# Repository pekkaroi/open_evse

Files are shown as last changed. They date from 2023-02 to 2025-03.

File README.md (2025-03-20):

# OpenEVSE

My fork has support for two contactors - one for 1 phase and one for 3 phase, and user can select the relay before starting charging. Change of the relay is forbidden during charging. To change the number of phases (to match with excess solar production), I have implemented a EspHome component connected to my OpenEvse directly with uart, and it first disables the charger (sleep), changes the relay to use, and then re-enables charge.

Additionally, as I accidentially ordered AtMega 328pb chips instead of 328p for my build, I had to modify the source accordinly.

Firmware for OpenEVSE controller used in OpenEVSE Charging Stations sold in the USA, and OpenEnergyMonitor EmonEVSE units sold in (UK/EU).

- OpenEVSE: <https://store.openevse.com/collections/all-products>
- EmonEVSE: <https://shop.openenergymonitor.com/evse/>

Based on OpenEVSE: Open Source Hardware J1772 Electric Vehicle Supply Equipment

## USA

TODO: add notes about USA OpenEVSE

## UK/EU

- Disable `AUTOSVCLEVEL` (autodetection is designed for split-phase)
- Charging level default to `L2`
- Set `MAX_CURRENT_CAPACITY_L2 32` (limit for single-phase charging in UK/EU)
- Add '.EU' to version number
- Enable LCD Redraw every couple of min (required for EMC/CE)

### EmonEVSE

EmonEVSE (non-tethered type-2 EVSE unit)

- `PP_AUTO_AMPACITY` enabled to set max current based on non-tethered cable connected
- Three-phase option with `THREEPHASE` enabled to calculate three-phase energy ( Unneeded with ESP32_WiFi firmware >= 4.2

## API Documentation

- WIFI API: <http://github.com/openevse/ESP32_WiFi_V4.x/>
- RAPI API: <https://github.com/openenergymonitor/open_evse/blob/master/firmware/open_evse/rapi_proc.h>

## Resources

- [OpenEnergyMonitor OpenEVSE Setup Guide](https://guide.openenergymonitor.org/integrations/openevse)
- [OpenEnergyMonitor OpenEVSE Shop](https://shop.openenergymonitor.com/ev-charging/)

- [OpenEVSE Controller Datasheet](https://github.com/OpenEVSE/OpenEVSE_PLUS/blob/master/OpenEVSE_PLUS_v5/OpenEVSE_Plus_v5.pdf)
- [OpenEVSE Controller Hardware Repo](https://github.com/OpenEVSE/OpenEVSE_PLUS)
- [OpenEVSE Project Homepage](https://openevse.com)

***

Firmware compile & upload help: [firmware/open_evse/LoadingFirmware.md](firmware/open_evse/LoadingFirmware.md)

NOTES:

- Working versions of the required libraries are included with the firmware code. This avoids potential issues related to using the wrong versions of the libraries.
- Highly recommend using the tested pre-compiled firmware (see releases page)

## Flash pre-compiled using avrdude

`$ avrdude -p atmega328p -B6 -c usbasp -P usb -e -U flash:w:firmware.hex`

ISP programmer required e.g [USBASP](https://www.amazon.co.uk/Hobby-Components-USBASP-Programmer-Adapter/dp/B06XYV162N)

### Set AVR fuses

This only needs to be done once in the factory

`avrdude -c USBasp -p m328p -U lfuse:w:0xFF:m -U hfuse:w:0xDF:m -U efuse:w:0xFD:m -B6`

If writing eFuse fails ISBasp may need a [firmware update](https://www.vishnumaiea.in/articles/electronics/how-to-solve-usbasp-avr-efuse-write-problem-on-progisp)

***

Tip Jar: I developed/maintain this firmware on a volunteer basis. Any donation, no matter how small, is greatly appreciated.



```text
Open EVSE is free software; you can redistribute it and/or modify
it under the terms of the GNU General Public License as published by
the Free Software Foundation; either version 3, or (at your option)
any later version.

Open EVSE is distributed in the hope that it will be useful,
but WITHOUT ANY WARRANTY; without even the implied warranty of
MERCHANTABILITY or FITNESS FOR A PARTICULAR PURPOSE.  See the
GNU General Public License for more details.

You should have received a copy of the GNU General Public License
along with Open EVSE; see the file COPYING.  If not, write to the
Free Software Foundation, Inc., 59 Temple Place - Suite 330,
Boston, MA 02111-1307, USA.

* Open EVSE is distributed in the hope that it will be useful,
* but WITHOUT ANY WARRANTY; without even the implied warranty of
* MERCHANTABILITY or FITNESS FOR A PARTICULAR PURPOSE.
```

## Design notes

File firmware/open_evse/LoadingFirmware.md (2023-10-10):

# OpenEVSE Firmware Loading

## Introduction 

Loading firmware to the OpenEVSE requires an ISP. There are many AVR/Arduino compatible programmers available from Adafruit, Sparkfun and the OpenEVSE Store. The instructions below are based on the USBasp.

## USBasp Windows Driver

Current versions of avrdude used by Platform IO and Arduino IDE need the libusbK driver in order to function properly with generic USBasp clones.

1. Plug in USBasp
2. Download Zadig from http://zadig.akeo.ie
3. Start zadig
4. Options > List all devices
5. Select USBasp from the drop down menu
6. Select libusbK(v3.0.7.0) driver
7. Click Install

## Firmware Building and Uploading

The latest firmware source code is located in GitHub: https://github.com/lincomatic/open_evse/tree/development

The latest stable firmware source code is located in GitHub: https://github.com/OpenEVSE/open_evse

### Platform IO

#### 1. Install Platform IO

Either install the command line only [PlatformIO Core](http://docs.platformio.org/en/latest/installation.html) or the download the [PlatfomIO IDE](http://platformio.org/platformio-ide).

If you already have Atom or VS Code installed you can just install the [Atom package](https://atom.io/packages/platformio-ide) or [VSCode extension](https://marketplace.visualstudio.com/items?itemName=platformio.platformio-ide) respectively.

### Arduino IDE

<div class="alert alert-success">
Note: These following instructions have been extracted from Google Code and are not complete/properly edited
</div>

The Arduino IDE includes an code editor, serial monitor, and will compile and upload your code to the OpenEVSE.

Download and install the Arduino IDE from here: http://arduino.cc/en/Main/Software

In the Arduino Software you can simply select the Arduino UNO in the Tools - Boards menu or add a custom entry for OpenEVSE.

Optional - To add a custom board to Arduino IDE, copy the "boards.txt" to the folder ~\Arduino\hardware\openevse\avr.

```
#
open_evse.name=OpenEVSE

open_evse.bootloader.low_fuses=0xFF
open_evse.bootloader.high_fuses=0xDA
open_evse.bootloader.extended_fuses=0x05

open_evse.upload.using=avrispmkii
open_evse.upload.maximum_size=32768

open_evse.build.mcu=atmega328p
open_evse.build.f_cpu=16000000L
open_evse.core=arduino
open_evse.build.variant=standard
```

After you do that (and restart Arduino), you'll find a new entry in your Boards menu called "OpenEVSE". Select that when preparing to upload firmware.

#### 2. Compile

`$ pio run`

The first time platformIO is ran the AVR arduino tool chain and all the required libs will be installed if required.

#### 3. Upload

`$ pio run -t program`

### Setting Fuse Bits

If you are burning virgin chips, you must set the fuse bits prior to programming. Fuses only need to be set once and will retain the settings unless reset. If you've modified boards.txt as shown above, then select "burn bootloader" from the tools menu to set the fuses as appropriate. This step won't actually load a bootloader. It will simply set the fuses.

See also: https://code.google.com/p/open-evse/wiki/AVRDUDE for how to accomplish this.

## Enabling features

To enable a feature delete the `//` in front of the #define tag. To disable a feature add `//`...

Example to enable the Advanced Power Supply features (`ADVPWR`) Change the line:

```
//#define ADVPWR
```

to

```
define ADVPWR
```

Note: Use Extreme caution with WATCHDOG, if delays were added that exceed the timer the EVSE board will reset in an endless loop. It may be very difficult or impossible to recover.

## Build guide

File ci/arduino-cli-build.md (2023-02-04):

# OpenEVSE build via Arduino CLI

Setup

```bash
arduino-cli core update-index
arduino-cli core install arduino:avr@1.6.15
cp arduino/1.6.15/boards.local.txt ~/.arduino15/packages/arduino/hardware/avr/1.6.15/
cp arduino/1.6.15/programmers.txt ~/.arduino15/packages/arduino/hardware/avr/1.6.15/
```

Build

```bash
arduino-cli compile -b arduino:avr:openevse firmware/open_evse
```

Upload

```bash
arduino-cli upload -b arduino:avr:openevse -P usbasp firmware/open_evse -v
```

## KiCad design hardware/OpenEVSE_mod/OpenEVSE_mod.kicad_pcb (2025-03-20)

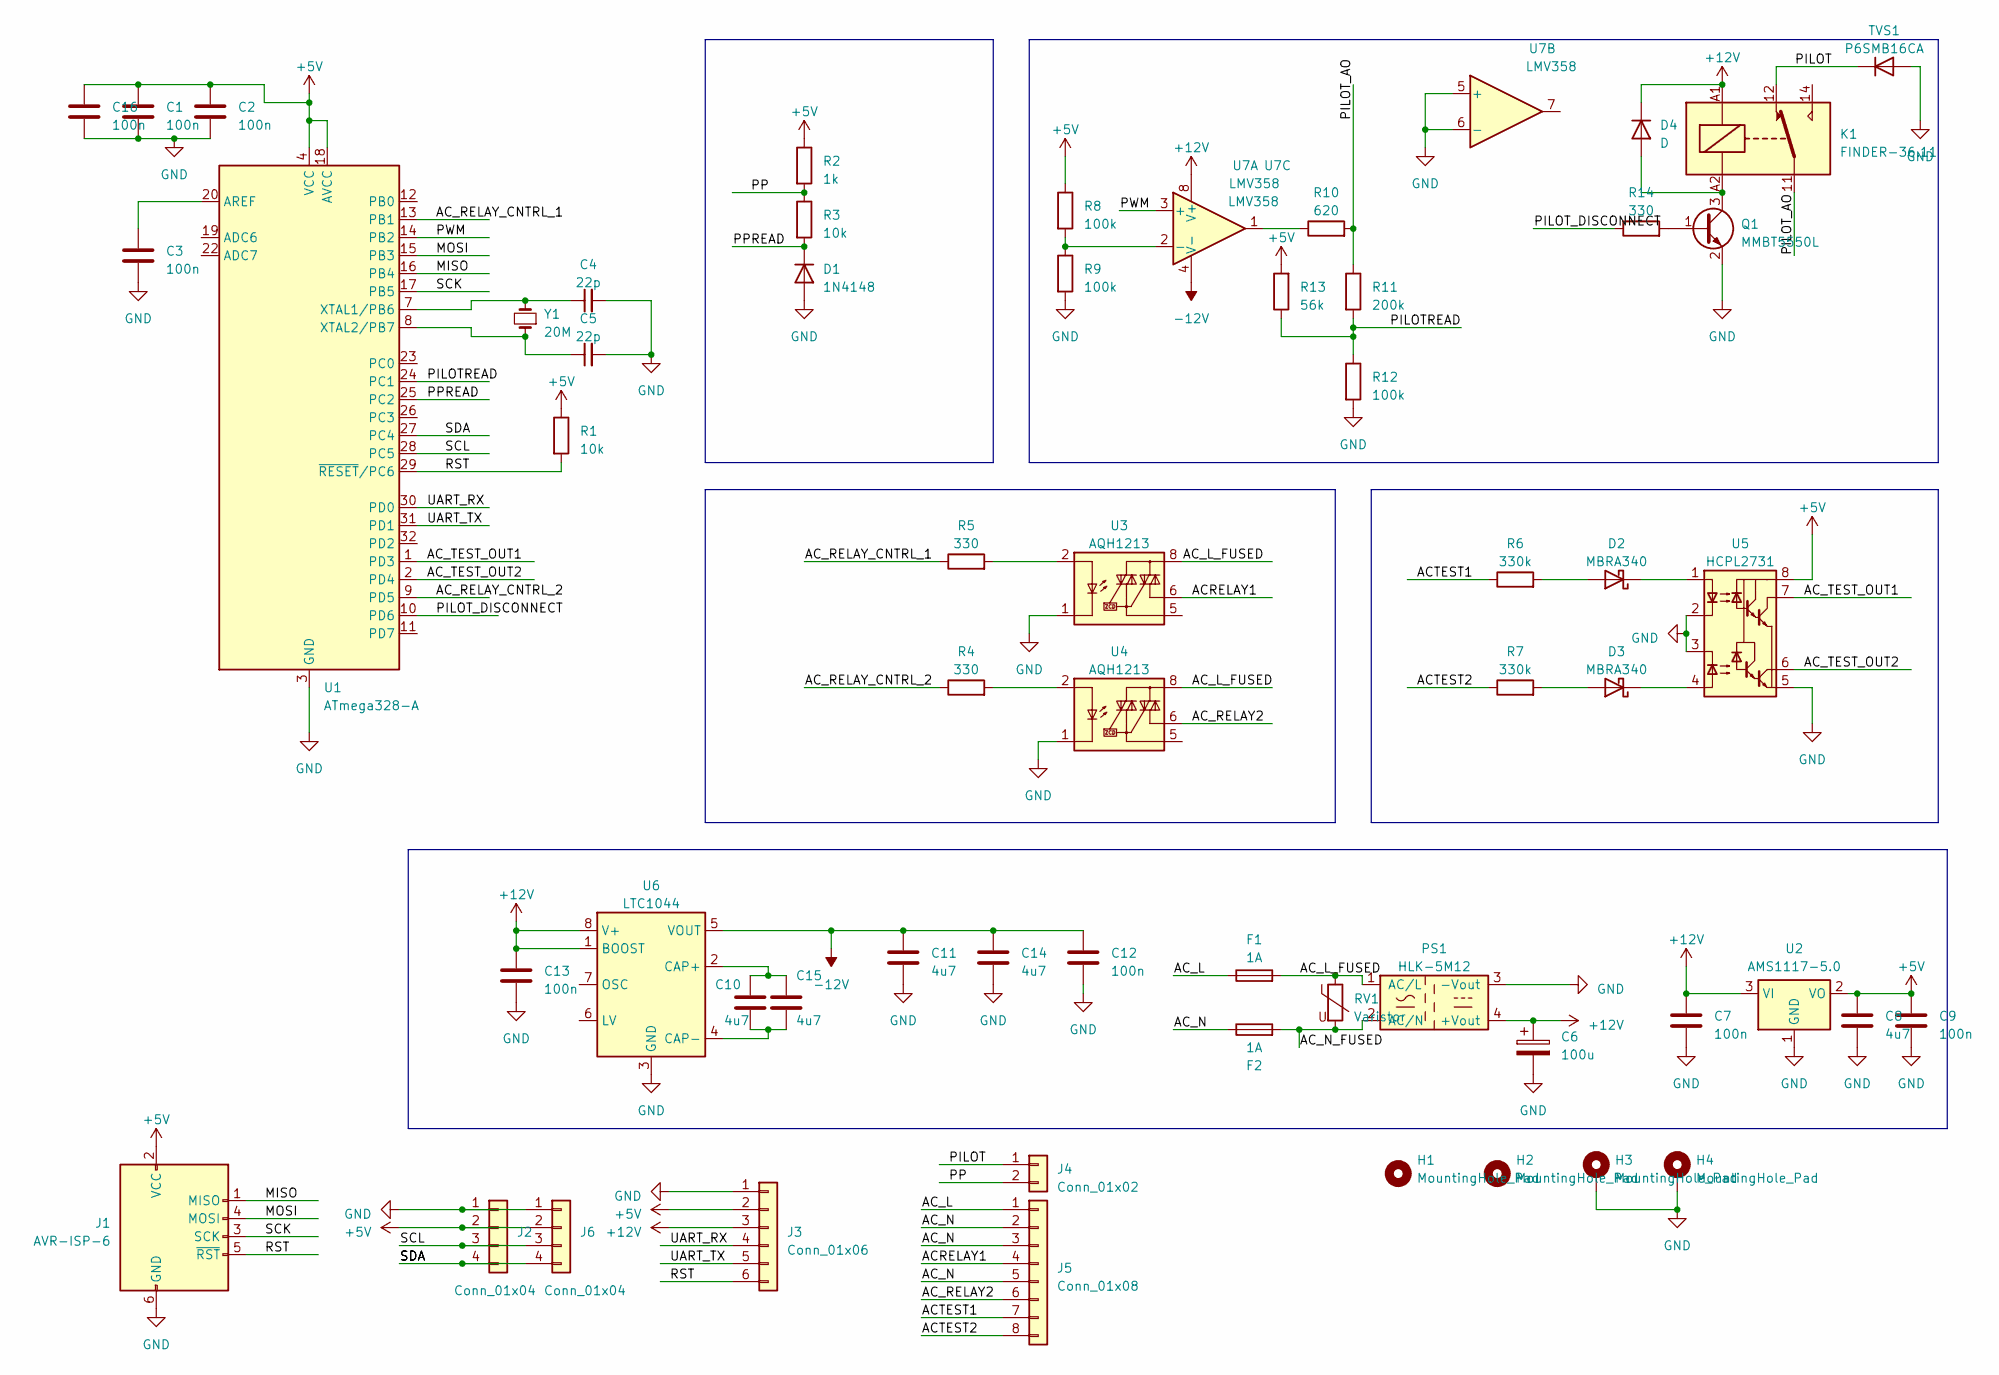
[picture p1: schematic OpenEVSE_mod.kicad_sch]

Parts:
C1, C2, C3, C7, C9, C12, C13, C16: 100n; C_0805_2012Metric_Pad1.18x1.45mm_HandSolder
C4, C5: 22p; C_0805_2012Metric_Pad1.18x1.45mm_HandSolder
C6: 100u; CP_Radial_D8.0mm_P3.50mm
C8, C10, C11, C14, C15: 4u7; C_0805_2012Metric_Pad1.18x1.45mm_HandSolder
D1: 1N4148; D_0402_1005Metric_Pad0.77x0.64mm_HandSolder
D2, D3: MBRA340; D_SMA
D4: D; D_SMB-SMC_Universal_Handsoldering
F1, F2: 1A; Fuse_Littelfuse_395Series
H1, H2: MountingHole_Pad; MountingHole_3.2mm_M3_ISO14580
H3, H4: MountingHole_Pad; MountingHole_3.2mm_M3_ISO14580_Pad_TopBottom
J1: AVR-ISP-6; PinHeader_2x03_P2.54mm_Vertical
J2, J6: Conn_01x04; PinSocket_1x04_P2.54mm_Vertical
J3: Conn_01x06; PinSocket_1x06_P2.54mm_Vertical
J4: Conn_01x02; TerminalBlock_Phoenix_PT-1,5-2-5.0-H_1x02_P5.00mm_Horizontal
J5: Conn_01x08; TerminalBlock_Phoenix_PT-1,5-8-5.0-H_1x08_P5.00mm_Horizontal
K1: FINDER-36.11; Relay_SPDT_Finder_36.11
PS1: HLK-5M12; Converter_ACDC_Hi-Link_HLK-5MXX_THT
Q1: MMBT5550L; SOT-23
R1, R3: 10k; R_0805_2012Metric_Pad1.20x1.40mm_HandSolder
R2: 1k; R_0805_2012Metric_Pad1.20x1.40mm_HandSolder
R4, R5, R14: 330; R_0805_2012Metric_Pad1.20x1.40mm_HandSolder
R6, R7: 330k; R_Axial_DIN0309_L9.0mm_D3.2mm_P15.24mm_Horizontal
R8, R9, R12: 100k; R_0805_2012Metric_Pad1.20x1.40mm_HandSolder
R10: 620; R_0805_2012Metric_Pad1.20x1.40mm_HandSolder
R11: 200k; R_0805_2012Metric_Pad1.20x1.40mm_HandSolder
R13: 56k; R_0805_2012Metric_Pad1.20x1.40mm_HandSolder
RV1: Varistor; RV_Disc_D12mm_W3.9mm_P7.5mm
TVS1: P6SMB16CA; D_SMB_Handsoldering
U1: ATmega328-A; TQFP-32_7x7mm_P0.8mm
U2: AMS1117-5.0; SOT-223-3_TabPin2
U3, U4: AQH1213; DIP-8-N7_W7.62mm
U5: HCPL2731; DIP-8_W7.62mm
U6: LTC1044; SOIC-8_3.9x4.9mm_P1.27mm
U7: LMV358; SOIC-8_3.9x4.9mm_P1.27mm
Y1: 20M; Crystal_HC49-U_Vertical

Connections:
+5V: C1.1, C2.1, C8.1, C9.1, C16.1, J1.2 (VCC), J2.2, J3.2, J6.2, R1.1, R2.1, R8.1, R13.2, U1.4 (VCC), U1.6 (VCC), U1.18 (AVCC), U2.2 (VO), U5.8 (VCC)
+12V: C6.1, C7.1, C13.1, D4.1 (K), J3.3, K1.A1, PS1.4 (+Vout), U2.3 (VI), U6.1 (BOOST), U6.8 (V+), U7.8 (V+)
-12V: C11.1, C12.1, C14.1, U6.5 (VOUT), U7.4 (V-)
/ACRELAY1: J5.4, U3.6
/ACTEST1: J5.7, R6.1
/ACTEST2: J5.8, R7.1
/AC_L: F1.1, J5.1
/AC_L_FUSED: F1.2, PS1.1 (AC/L), RV1.1, U3.8, U4.8
/AC_N: F2.1, J5.2, J5.3, J5.5
/AC_N_FUSED: F2.2, PS1.2 (AC/N), RV1.2
/AC_RELAY2: J5.6, U4.6
/AC_RELAY_CNTRL_1: R5.1, U1.13 (PB1)
/AC_RELAY_CNTRL_2: R4.1, U1.9 (PD5)
/AC_TEST_OUT1: U1.1 (PD3), U5.7 (VO1)
/AC_TEST_OUT2: U1.2 (PD4), U5.6 (VO2)
/MISO: J1.1 (MISO), U1.16 (PB4)
/MOSI: J1.4 (MOSI), U1.15 (PB3)
/PILOT: J4.1, K1.12, TVS1.1 (K)
/PILOTREAD: R11.2, R12.1, R13.1, U1.24 (PC1)
/PILOT_AO: K1.11, R10.2, R11.1
/PILOT_DISCONNECT: R14.1, U1.10 (PD6)
/PP: J4.2, R2.2, R3.1
/PPREAD: D1.1 (K), R3.2, U1.25 (PC2)
/PWM: U1.14 (PB2), U7.3 (+)
/RST: J1.5 (~RST), J3.6, R1.2, U1.29 (~RESET/PC6)
/SCK: J1.3 (SCK), U1.17 (PB5)
/SCL: J2.3, J6.3, U1.28 (PC5)
/SDA: J2.4, J6.4, U1.27 (PC4)
/UART_RX: J3.4, U1.30 (PD0)
/UART_TX: J3.5, U1.31 (PD1)
GND: C1.2, C2.2, C3.2, C4.2, C5.2, C6.2, C7.2, C8.2, C9.2, C11.2, C12.2, C13.2, C14.2, C16.2, D1.2 (A), H3.1, H4.1, J1.6 (GND), J2.1, J3.1, J6.1, PS1.3 (-Vout), Q1.2 (E), R9.2, R12.2, TVS1.2 (A), U1.3 (GND), U1.5 (GND), U1.21 (GND), U2.1 (GND), U3.1, U3.3, U3.4, U4.1, U4.3, U4.4, U5.2 (C1), U5.3 (C2), U5.5 (GND), U6.3 (GND), U7.5 (+), U7.6 (-)
unnamed: D2.2 (A), R6.2
unnamed: D2.1 (K), U5.1 (A1)
unnamed: D3.2 (A), R7.2
unnamed: D3.1 (K), U5.4 (A2)
unnamed: D4.2 (A), K1.A2, Q1.3 (C)
unnamed: Q1.1 (B), R14.2
unnamed: R4.2, U4.2
unnamed: R5.2, U3.2
unnamed: R10.1, U7.1
unnamed: C3.1, U1.20 (AREF)
unnamed: C4.1, U1.7 (XTAL1/PB6), Y1.2
unnamed: C5.1, U1.8 (XTAL2/PB7), Y1.1
unnamed: C10.1, C15.1, U6.2 (CAP+)
unnamed: C10.2, C15.2, U6.4 (CAP-)
unnamed: R8.2, R9.1, U7.2 (-)

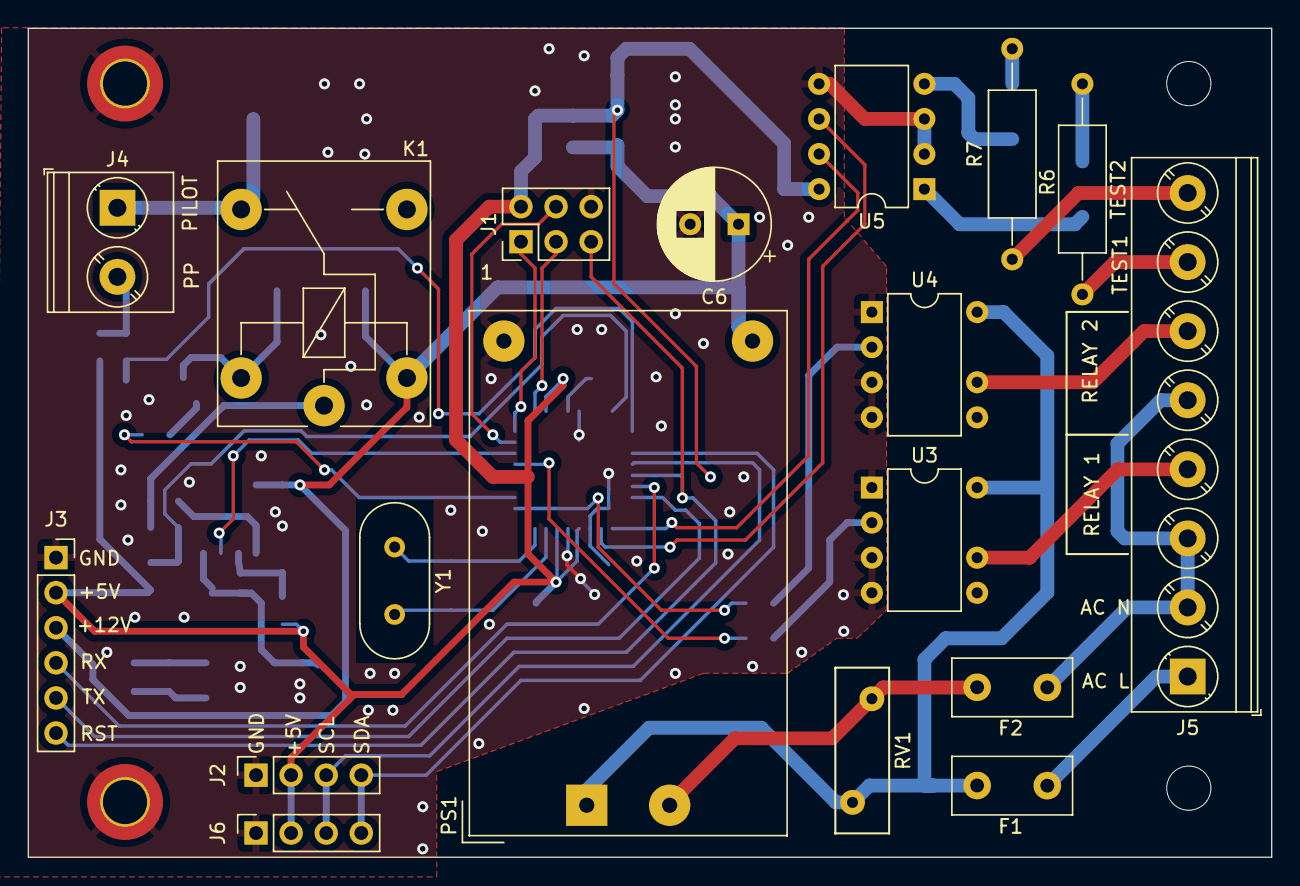
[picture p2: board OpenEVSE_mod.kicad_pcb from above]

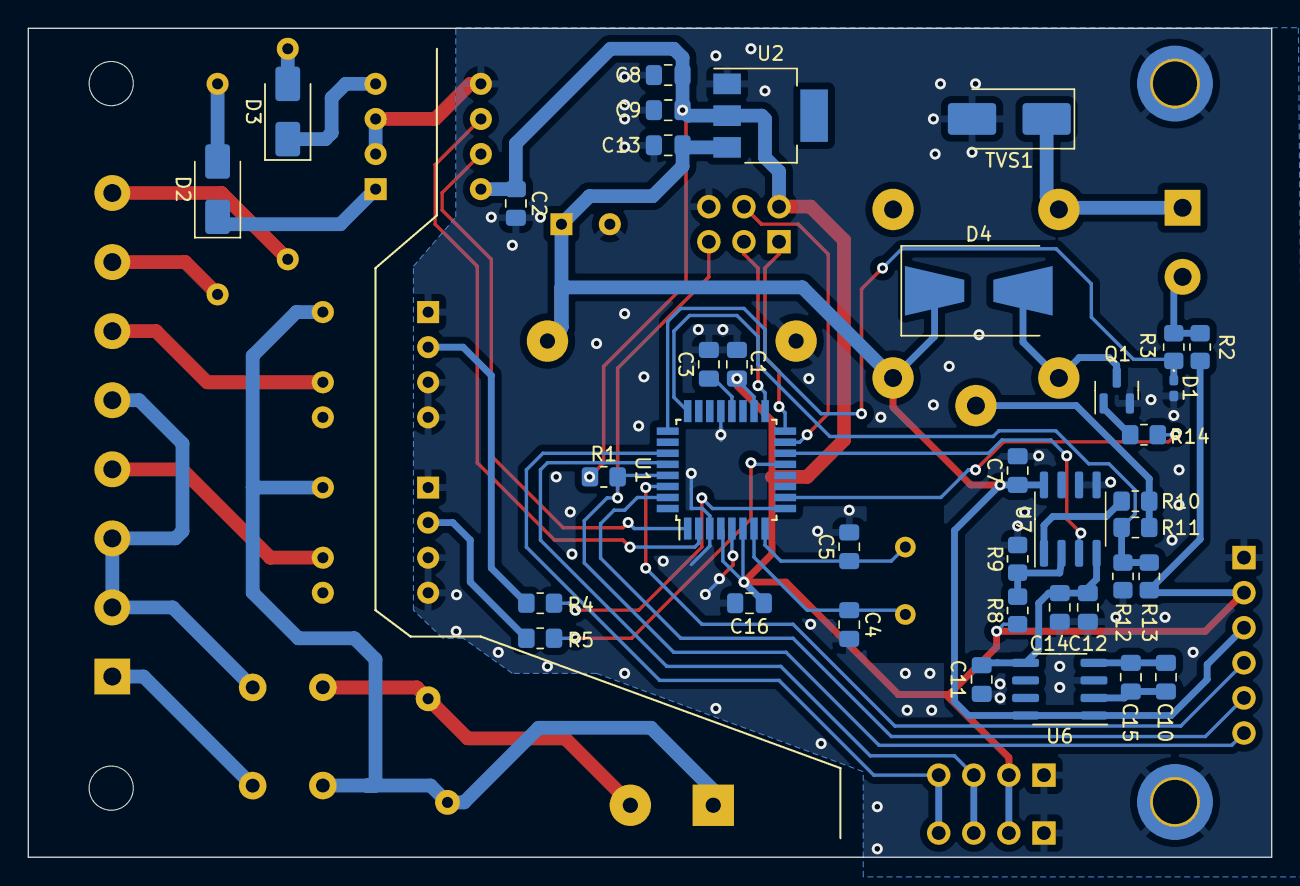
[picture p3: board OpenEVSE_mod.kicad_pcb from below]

Board: 2 copper layers, 90.0 x 60.0 mm, 59 parts (38 on the bottom side), 46 nets.

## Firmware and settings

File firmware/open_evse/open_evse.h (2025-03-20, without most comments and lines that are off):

#pragma once
#define OPEN_EVSE
#include <avr/wdt.h>
#include <avr/pgmspace.h>
#include <avr/eeprom.h>
#include <pins_arduino.h>
#include "./Wire.h"
#include "avrstuff.h"
#include "i2caddr.h"
#if defined(ARDUINO) && (ARDUINO >= 100)
#include "Arduino.h"
#else
#include "WProgram.h" // shouldn't need this but arduino sometimes messes up and puts inside an #ifdef
#endif // ARDUINO
#define setBits(flags,bits) (flags |= (bits))
#define clrBits(flags,bits) (flags &= ~(bits))
#define VERSION "8.2.3 PERO"
#include "Language_default.h"   //Default language should always be included as bottom layer
typedef unsigned long time_t;
#ifndef PLATFORMIO
#define OEV6
#ifdef OEV6
#define RELAY_PWM
#define RELAY_HOLD_DELAY_TUNING // enable Z0
#endif // OEV6
#ifndef NO_AUTOSVCLEVEL
#define AUTOSVCLEVEL
#endif
#define SHOW_DISABLED_TESTS
#define AMMETER
#define RAPI
#define RAPI_SERIAL
#define RAPI_WF
#define RAPI_BTN
#define TIME_LIMIT
#define CHARGE_LIMIT
#define MENNEKES_LOCK
#endif // !PLATFORMIO
#define MCU_ID_LEN 10
#define WATCHDOG
#define TEMPERATURE_MONITORING  // Temperature monitoring support
#ifdef AMMETER
#define MV_FOR_L1 120000L       // conventional for North America
#define MV_FOR_L2 240000L       // conventional for North America
#define KWH_RECORDING
#ifdef KWH_RECORDING
#define KWH_CALC_INTERVAL_MS (250UL)
#include "EnergyMeter.h"
#endif // KWH_RECORDING
#endif //AMMETER
#define BKL_TYPE_MONO 0
#define BKL_TYPE_RGB  1
#define DEFAULT_LCD_BKL_TYPE BKL_TYPE_MONO
#define ADVPWR
#define NOSETUP_MENU
#define BTN_ENABLE_TOGGLE
#//define RTC // enable RTC & timer functions
#ifdef RTC
#define DELAYTIMER
#if defined(DELAYTIMER) && defined(BTN_MENU)
#define DELAYTIMER_MENU
#endif
#else // !RTC
#define GPPBUGKLUDGE
#endif // RTC
#define PAFC_PWM
#define DEFAULT_RELAY_CLOSE_MS 100
#define DEFAULT_RELAY_HOLD_PWM 255 // (0-255, where 0=0%, 255=100%
#undef BTN_MENU
#if defined(OPENEVSE_2) && !defined(ADVPWR)
#error INVALID CONFIG - OPENEVSE_2 implies/requires ADVPWR
#endif
#if defined(UL_COMPLIANT) && !defined(GFI_SELFTEST)
#error INVALID CONFIG - GFI SELF TEST NEEDED FOR UL COMPLIANCE
#endif
#if defined(GFI_SELFTEST) && !defined(GFI)
#error INVALID_CONFIG - GFI NEEDED FOR GFI SELF TEST
#endif
#define WATCHDOG_TIMEOUT WDTO_2S
#define LCD_MAX_CHARS_PER_LINE 16
#define TMP_BUF_SIZE ((LCD_MAX_CHARS_PER_LINE+1)*2)
#define DEFAULT_SERVICE_LEVEL 2 // 1=L1, 2=L2
#define DEFAULT_CURRENT_CAPACITY_L1 12
#define DEFAULT_CURRENT_CAPACITY_L2 24
#define MIN_CURRENT_CAPACITY_J1772 6
#define MAX_CURRENT_CAPACITY_L1 24 // J1772 Max for L1 on a 20A circuit = 16, 15A circuit = 12 Some Vehicles suppoty 24A on 30A RV outlet TT-30
#define MAX_CURRENT_CAPACITY_L2 80 // J1772 Max for L2 = 80
#define CURRENT_PIN 0 // analog current reading pin ADCx
#define PILOT_PIN 1 // analog pilot voltage reading pin ADCx
#define PP_PIN 2 // PP_READ - ADC2
#define ACLINE1_REG &PIND
#define ACLINE1_IDX 3
#define ACLINE2_REG &PIND
#define ACLINE2_IDX 4
#define V6_CHARGING_PIN  5
#define V6_CHARGING_PIN2 6
#define CHARGINGAC3P_REG &PINB
#define CHARGINGAC3P_IDX 1
#define CHARGINGAC1P_REG &PIND
#define CHARGINGAC1P_IDX 5
#define PILOT_REG &PINB
#define PILOT_IDX 2
#ifdef MENNEKES_LOCK
#define MENNEKES_LOCK_PINA_REG &PINB
#define MENNEKES_LOCK_PINA_IDX 3
#define MENNEKES_LOCK_PINB_REG &PINB
#define MENNEKES_LOCK_PINB_IDX 4
#include "MennekesLock.h"
#endif // MENNEKES_LOCK
#define SERIAL_BAUD 38400
#define EOFS_CURRENT_CAPACITY_L1 0 // 1 byte
#define EOFS_CURRENT_CAPACITY_L2 1 // 1 byte
#define EOFS_FLAGS               2 // 2 bytes
#define EOFS_TIMER_FLAGS         4 // 1 byte
#define EOFS_TIMER_START_HOUR    5 // 1 byte
#define EOFS_TIMER_START_MIN     6 // 1 byte
#define EOFS_TIMER_STOP_HOUR     7 // 1 byte
#define EOFS_TIMER_STOP_MIN      8 // 1 byte
#define EOFS_CURRENT_SCALE_FACTOR 9 // 2 bytes
#define EOFS_AMMETER_CURR_OFFSET  11 // 2 bytes
#define EOFS_KWH_ACCUMULATED 13 // 4 bytes
#define EOFS_GFI_TRIP_CNT      17 // 1 byte
#define EOFS_NOGND_TRIP_CNT    18 // 1 byte
#define EOFS_STUCK_RELAY_TRIP_CNT 19 // 1 byte
#define EOFS_VOLT_OFFSET 20 // 4 bytes
#define EOFS_VOLT_SCALE_FACTOR 24 // 2 bytes
#define EOFS_THRESH_AMBIENT 26 // 2 bytes
#define EOFS_THRESH_IR 28 // 2 bytes
#define EOFS_LOCAL_I2C_ADDR 30 // 1 byte
#define EOFS_GROUP_CURRENT_CAPACITY 31 // 1 byte
#define EOFS_DUO_NVFLAGS 32 // 1 byte
#define EOFS_DUO_SHARED_AMPS 33 // 1 byte
#define EOFS_HEARTBEAT_SUPERVISION_INTERVAL 34 // 2 bytes (zero if infinite)
#define EOFS_HEARTBEAT_SUPERVISION_CURRENT 36 // 1 byte
#define EOFS_RELAY_CLOSE_MS 37 // 1 byte
#define EOFS_RELAY_HOLD_PWM 38 // 1 byte
#define EOFS_MAX_HW_CURRENT_CAPACITY 511 // 1 byte
#define DELAY_STATE_TRANSITION 250
#define DELAY_STATE_TRANSITION_A 25
#define GROUND_CHK_DELAY  1000 // delay after charging started to test, ms
#define STUCK_RELAY_DELAY 1000 // delay after charging opened to test, ms
#define RelaySettlingTime  250 // time for relay to settle in post, ms
#define AC_SAMPLE_MS 20 // 1 cycle @ 60Hz = 16.6667ms @ 50Hz = 20ms
#define V6_ID_REG D
#define V6_ID_IDX 7
#define GFI_TIMEOUT ((unsigned long)(5*60000)) // 15*60*1000 doesn't work. go figure
#define GFI_RETRY_COUNT  6
#define RED 0x1
#define YELLOW 0x3
#define GREEN 0x2
#define BLUE 0x4
#define TEAL 0x6
#define VIOLET 0x5
#define WHITE 0x7
#define BTN_REG &PINC
#define BTN_IDX 3
#define BTN_PRESS_SHORT 50  // ms
#define BTN_PRESS_LONG 500 // ms
#define BTN_PRESS_VERYLONG 10000
#ifdef RTC
#define DEFAULT_START_HOUR    0x00 //Start time: 00:05
#define DEFAULT_START_MIN     0x05
#define DEFAULT_STOP_HOUR     0x06 //End time: 6:55
#define DEFAULT_STOP_MIN      0x37
#endif // RTC
#define PILOT_LOOP_CNT 100
#ifdef AMMETER
#define DEFAULT_CURRENT_SCALE_FACTOR 220   // OpenEVSE v2.5 and v3 with a 22 Ohm burden resistor (note that the schematic may say 28 Ohms by mistake)
#define DEFAULT_AMMETER_CURRENT_OFFSET 0   // OpenEVSE v2.5 and v3 with a 22 Ohm burden resistor.  Could use a more thorough calibration exercise to nails this down.
#define CURRENT_SAMPLE_INTERVAL 35
#define CURRENT_ZERO_DEBOUNCE_INTERVAL 5
#endif // AMMETER
#define MCP9808_IS_ON_I2C    // Use the MCP9808 connected to I2C
#define TEMPERATURE_DISPLAY_ALWAYS 0     // Set this flag to 1 to always show temperatures on the bottom line of the 16X2 LCD
#define TEMPERATURE_AMBIENT_THROTTLE_DOWN 650
#define TEMPERATURE_AMBIENT_RESTORE_AMPERAGE 620
#define TEMPERATURE_AMBIENT_SHUTDOWN 680
#define TEMPERATURE_AMBIENT_PANIC 710
#define TEMPERATURE_INFRARED_THROTTLE_DOWN 650    // This is the temperature seen  by the IR sensor where we tell the car to draw 1/2 amperage.
#define TEMPERATURE_INFRARED_RESTORE_AMPERAGE 600 // If the OpenEVSE responds nicely to the lower current drawn and temperatures in the enclosure
#define TEMPERATURE_INFRARED_SHUTDOWN 700         // This is the temperature in the enclosure where we tell the car to draw 1/4 amperage or 6A is minimum.
#define TEMPERATURE_INFRARED_PANIC 750            //  At this temperature gracefully tell the EV to quit drawing any current, and leave the EVSE in
#define SHOW_DISABLED_DELAY 1500
typedef union union4b {
  int8_t i8;
  uint8_t u8;
  int16_t i16;
  uint16_t u16;
  int32_t i32;
  uint32_t u32;
  unsigned u;
  int i;
} UNION4B,*PUNION4B;
#define WDT_RESET() wdt_reset() // pat the dog
#define WDT_ENABLE() wdt_enable(WATCHDOG_TIMEOUT)
#define OBDF_MONO_BACKLIGHT 0x01
#define OBDF_AMMETER_DIRTY  0x80
#define OBDF_UPDATE_DISABLED 0x40
#define OBD_UPD_NORMAL    0
#define OBD_UPD_FORCE     1 // update even if no state transition
#define OBD_UPD_HARDFAULT 2 // update w/ hard fault
class OnboardDisplay
{
  uint8_t m_bFlags;
  char m_strBuf[LCD_MAX_CHARS_PER_LINE+1];
  unsigned long m_LastUpdateMs;
  int8_t updateDisabled() { return  m_bFlags & OBDF_UPDATE_DISABLED; }
  void MakeChar(uint8_t n, PGM_P bytes);
public:
  OnboardDisplay();
  void Init();
  void SetGreenLed(uint8_t state) {
  }
  void SetRedLed(uint8_t state) {
  }
#ifdef AMMETER
  void SetAmmeterDirty(uint8_t tf) {
    if (tf) m_bFlags |= OBDF_AMMETER_DIRTY;
    else m_bFlags &= ~OBDF_AMMETER_DIRTY;
  }
  int8_t AmmeterIsDirty() { return (m_bFlags & OBDF_AMMETER_DIRTY) ? 1 : 0; }
#endif // AMMETER
  void DisableUpdate(int8_t on) {
    if (on) m_bFlags |= OBDF_UPDATE_DISABLED;
    else m_bFlags &= ~OBDF_UPDATE_DISABLED;
  }
  int8_t UpdatesDisabled() { return (m_bFlags & OBDF_UPDATE_DISABLED) ? 1 : 0; }
  void Update(int8_t updmode=OBD_UPD_NORMAL); // OBD_UPD_xxx
};
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

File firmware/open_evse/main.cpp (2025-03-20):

// -*- C++ -*-
/*
 * Open EVSE Firmware
 *
 * Copyright (c) 2011-2023 Sam C. Lin
 * Copyright (c) 2011-2014 Chris Howell <chris1howell@msn.com>
 * timer code Copyright (c) 2013 Kevin L <goldserve1@hotmail.com>
 * portions Copyright (c) 2014-2015 Nick Sayer <nsayer@kfu.com>
 * portions Copyright (c) 2015 Craig Kirkpatrick
 * portions Copyright (c) 2015 William McBrine
 * portions Copyright (c) 2019 Tim Kuechler BowElectric at gmail

 Revised  Ver	By		Reason
 6/21/13  20b3	Scott Rubin	fixed LCD display bugs with RTC enabled
 6/25/13  20b4	Scott Rubin	fixed LCD display bugs, CLI fixes, when RTC disabled
 6/30/13  20b5	Scott Rubin	added LcdDetected() function, prevents hang if LCD not installed
 7/06/13  20b5	Scott Rubin	rewrote power detection in POST function for 1 or 2 relays
 7/11/13  20b5	Scott Rubin	skips POST if EV is connected, won't charge if open ground or stuck relay
 8/12/13  20b5b Scott Rubin    fix GFI error - changed gfi.Reset() to check for constant GFI signal
 8/26/13  20b6 Scott Rubin     add Stuck Relay State delay, fix Stuck Relay state exit (for Active E)
 9/20/13  20b7 Chris Howell    updated/tweaked/shortened CLI messages   
 10/25/14      Craig K         add smoothing to the Amperage readout
 3/1/15        Craig K         add TEMPERATURE_MONITORING
 3/7/15        Craig K         add KWH_RECORDING
 10/28/2019    Tim Kuechler    add HEARTBEAT_SUPERVISION
  
 * This file is part of Open EVSE.

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
 * You should have received a copy of the GNU General Public License
 * along with Open EVSE; see the file COPYING.  If not, write to the
 * Free Software Foundation, Inc., 59 Temple Place - Suite 330,
 * Boston, MA 02111-1307, USA.
 */
#include <avr/io.h>
#include <avr/eeprom.h>
#include <avr/wdt.h>
#include <avr/pgmspace.h>
#include <pins_arduino.h>
#include "./Wire.h"
#include "./RTClib.h"
#include "open_evse.h"

// if using I2CLCD_PCF8574 uncomment below line  and comment out LiquidTWI2.h above
//#include "./LiquidCrystal_I2C.h"
#ifdef TEMPERATURE_MONITORING
  #ifdef MCP9808_IS_ON_I2C
  #include "MCP9808.h"  //  adding the ambient temp sensor to I2C
  #endif 
  #ifdef TMP007_IS_ON_I2C
  #include "./Adafruit_TMP007.h"   //  adding the TMP007 IR I2C sensor
  #endif 
#endif // TEMPERATURE_MONITORING


#ifdef BTN_MENU
SettingsMenu g_SettingsMenu;
SetupMenu g_SetupMenu;
MaxCurrentMenu g_MaxCurrentMenu;
#ifndef NOSETUP_MENU
SvcLevelMenu g_SvcLevelMenu;
DiodeChkMenu g_DiodeChkMenu;
#ifdef RGBLCD
BklTypeMenu g_BklTypeMenu;
#endif // RGBLCD
#ifdef GFI_SELFTEST
GfiTestMenu g_GfiTestMenu;
#endif
#ifdef TEMPERATURE_MONITORING
TempOnOffMenu g_TempOnOffMenu;
#endif // TEMPERATURE_MONITORING
VentReqMenu g_VentReqMenu;
#ifdef ADVPWR
GndChkMenu g_GndChkMenu;
RlyChkMenu g_RlyChkMenu;
#endif // ADVPWR
#endif // NOSETUP_MENU
ResetMenu g_ResetMenu;
// Instantiate additional Menus - GoldServe
#if defined(DELAYTIMER_MENU)
RTCMenu g_RTCMenu;
RTCMenuMonth g_RTCMenuMonth;
RTCMenuDay g_RTCMenuDay;
RTCMenuYear g_RTCMenuYear;
RTCMenuHour g_RTCMenuHour;
RTCMenuMinute g_RTCMenuMinute;
DelayMenu g_DelayMenu;
DelayMenuEnableDisable g_DelayMenuEnableDisable;
DelayMenuStartHour g_DelayMenuStartHour;
DelayMenuStopHour g_DelayMenuStopHour;
DelayMenuStartMin g_DelayMenuStartMin;
DelayMenuStopMin g_DelayMenuStopMin;
#endif // DELAYTIMER_MENU
#ifdef CHARGE_LIMIT
ChargeLimitMenu g_ChargeLimitMenu;
#endif // CHARGE_LIMIT
#ifdef TIME_LIMIT
TimeLimitMenu g_TimeLimitMenu;
#endif // TIME_LIMIT


Menu *g_SettingsMenuList[] = {
#ifdef TIME_LIMIT
  &g_TimeLimitMenu,
#endif // TIME_LIMIT
#ifdef CHARGE_LIMIT
  &g_ChargeLimitMenu,
#endif // CHARGE_LIMIT
#ifdef DELAYTIMER_MENU
  &g_DelayMenu,
#endif // DELAYTIMER_MENU
  &g_SetupMenu,
  &g_ResetMenu,
  NULL
};

Menu *g_SetupMenuList[] = {
#ifdef NOSETUP_MENU
  &g_MaxCurrentMenu,
  &g_RTCMenu,
#else // !NOSETUP_MENU
#ifdef DELAYTIMER_MENU
  &g_RTCMenu,
#endif // DELAYTIMER_MENU
#ifdef RGBLCD
  &g_BklTypeMenu,
#endif // RGBLCD
  &g_SvcLevelMenu,
  &g_DiodeChkMenu,
  &g_VentReqMenu,
#ifdef ADVPWR
  &g_GndChkMenu,
  &g_RlyChkMenu,
#endif // ADVPWR
#ifdef GFI_SELFTEST
  &g_GfiTestMenu,
#endif // GFI_SELFTEST
#ifdef TEMPERATURE_MONITORING
  &g_TempOnOffMenu,
#endif // TEMPERATURE_MONITORING
#endif // NOSETUP_MENU
  NULL
};

BtnHandler g_BtnHandler;
#endif // BTN_MENU

#define g_sHHMMfmt "%02d:%02d"

//-- begin global variables

char g_sTmp[TMP_BUF_SIZE];

OnboardDisplay g_OBD;

// Instantiate RTC and Delay Timer - GoldServe
#ifdef RTC
RTC_DS1307 g_RTC;

#if defined(RAPI)
void SetRTC(uint8_t y,uint8_t m,uint8_t d,uint8_t h,uint8_t mn,uint8_t s) {
  g_RTC.adjust(DateTime(y,m,d,h,mn,s));
}
void GetRTC(char *buf) {
  DateTime t = g_RTC.now();
  sprintf(buf,"%d %d %d %d %d %d",t.year()-2000,t.month(),t.day(),t.hour(),t.minute(),t.second());
}
#endif // RAPI
#endif // RTC
#ifdef DELAYTIMER
DelayTimer g_DelayTimer;
#ifdef DELAYTIMER_MENU
// Start variables to support RTC and Delay Timer - GoldServe
uint16_t g_year;
uint8_t g_month;
uint8_t g_day;
uint8_t g_hour;
uint8_t g_min;
#endif // DELAYTIMER_MENU
#endif // DELAYTIMER


#ifdef TEMPERATURE_MONITORING
TempMonitor g_TempMonitor;
#endif // TEMPERATURE_MONITORING

#ifdef PP_AUTO_AMPACITY
AutoCurrentCapacityController g_ACCController;
#endif

//-- end global variables

// watchdog-safe delay - use this when delay is longer than watchdog
// *do not* call this before WDT_ENABLE() is called
void wdt_delay(uint32_t ms)
{
  do {
    WDT_RESET();
    if (ms > WATCHDOG_TIMEOUT/2) {
      delay(WATCHDOG_TIMEOUT/2);
      ms -= WATCHDOG_TIMEOUT/2;
    }
    else {
      delay(ms);
      ms = 0;
    }
  } while(ms);
}

static inline void wiresend(uint8_t x) {
#if ARDUINO >= 100
  Wire.write((uint8_t)x);
#else
  Wire.send(x);
#endif
}

static inline uint8_t wirerecv(void) {
#if ARDUINO >= 100
  return Wire.read();
#else
  return Wire.receive();
#endif
}

// if digits > 0, zero pad w/ to # digits
// WARNING: This function uses the *end* of g_sTmp as its buffer
char *u2a(unsigned long x,int8_t digits)
{
  char *s = g_sTmp + sizeof(g_sTmp);

  *--s = 0;

  do {
    *--s = '0'+ x % 10;
    x /= 10;
    --digits;
  } while (x || digits > 0);

  return s;
}

// wdt_init turns off the watchdog timer after we use it
// to reboot

void wdt_init(void) __attribute__((naked,used)) __attribute__((section(".init3")));
void wdt_init(void)
{
  MCUSR = 0;
  wdt_disable();

  return;
}


#ifdef TEMPERATURE_MONITORING

void TempMonitor::Init()
{
  m_Flags = 0;
  m_MCP9808_temperature = TEMPERATURE_NOT_INSTALLED;  // 230 means 23.0C  Using an integer to save on floating point library use
  m_DS3231_temperature = TEMPERATURE_NOT_INSTALLED;   // the DS3231 RTC has a built in temperature sensor
  m_TMP007_temperature = TEMPERATURE_NOT_INSTALLED;

#ifdef TEMPERATURE_MONITORING_NY
  LoadThresh();
#endif

#ifdef MCP9808_IS_ON_I2C
  m_tempSensor.begin();
#endif // MCP9808_IS_ON_I2C

#ifdef TMP007_IS_ON_I2C
  m_tmp007.begin();
#endif // TMP007_IS_ON_I2C
}

void TempMonitor::Read()
{
  unsigned long curms = millis();
  if ((curms - m_LastUpdate) >= TEMPMONITOR_UPDATE_INTERVAL) {
#ifdef TMP007_IS_ON_I2C
    m_TMP007_temperature = m_tmp007.readObjTempC10();   //  using the TI TMP007 IR sensor
#endif
#ifdef MCP9808_IS_ON_I2C
    m_MCP9808_temperature = m_tempSensor.readAmbient();  // for the MCP9808
#endif

       
#ifdef RTC
#ifdef OPENEVSE_2
    m_DS3231_temperature = TEMPERATURE_NOT_INSTALLED;  // OpenEVSE II does not use the DS3231
#else // !OPENEVSE_2
    // This code chunk below reads the DS3231 RTC's internal temperature sensor            
    Wire.beginTransmission(DS1307_ADDRESS);
    wiresend(uint8_t(0x0e));
    wiresend( 0x20 );               // write bit 5 to initiate conversion of temperature
    Wire.endTransmission();            
             
    Wire.beginTransmission(DS1307_ADDRESS);
    wiresend(uint8_t(0x11));
    Wire.endTransmission();
	  
    if(Wire.requestFrom(DS1307_ADDRESS, 2)) {                           // detect presence of DS3231 on I2C while addressing to read from it
    m_DS3231_temperature = (((int16_t)wirerecv()) << 8) | (wirerecv()); // read upper and lower byte
    m_DS3231_temperature = m_DS3231_temperature >> 6;                   // lower 6 bits always zero, ignore them
    if (m_DS3231_temperature & 0x0200) m_DS3231_temperature |= 0xFE00;  // sign extend if a negative number since we shifted over by 6 bits
    m_DS3231_temperature = (m_DS3231_temperature * 10) / 4;             // handle this as 0.25C resolution
                                                                        // Note that the device's sign bit only pertains to the device's upper byte.
                                                                        // The small side effect is that -0.25, -0.5, and -0.75C actual temperatues
                                                                        // will be read from the device without negative sign, thus appearing as +0.25C...
                                                                        // There is no software workaround to this small hardware shortcoming.
                                                                        // Temperatures outside of these values work perfectly with 1/4 degree resolution.
                                                                        // I wrote this note so nobody wastes time trying to "fix" this in software
                                                                        // since fundamentally it is a hardware limitaion of the DS3231.
      }                                                                    
    else                                                                    
      m_DS3231_temperature = TEMPERATURE_NOT_INSTALLED;
    
#endif // OPENEVSE_2
#endif // RTC

    m_LastUpdate = curms;
  }
}
#endif // TEMPERATURE_MONITORING


OnboardDisplay::OnboardDisplay()
#if defined(I2CLCD) || defined(RGBLCD)
#ifdef I2CLCD_PCF8574
// Set the pins on the I2C chip used for LCD connections:
//                    addr, en,rw,rs,d4,d5,d6,d7,bl,blpol
  : m_Lcd(LCD_I2C_ADDR, 2, 1, 0, 4, 5, 6, 7, 3, POSITIVE)
#else
  : m_Lcd(LCD_I2C_ADDR,1)
#endif // I2CLCD_PCF8574
#endif // defined(I2CLCD) || defined(RGBLCD)
{
}


#if defined(DELAYTIMER)
const char CustomChar_6[8] PROGMEM = {0x0,0xe,0x15,0x17,0x11,0xe,0x0,0x0}; // clock
#endif
#ifdef DELAYTIMER
const char CustomChar_1[8] PROGMEM = {0x0,0x0,0xe,0xe,0xe,0x0,0x0,0x0}; // stop (cube)
const char CustomChar_2[8] PROGMEM = {0x0,0x8,0xc,0xe,0xc,0x8,0x0,0x0}; // play 
#endif // DELAYTIMER
#if defined(DELAYTIMER)||defined(CHARGE_LIMIT)
const char CustomChar_3[8] PROGMEM = {0x0,0xe,0xc,0x1f,0x3,0x6,0xc,0x8}; // lightning
#endif
#ifdef AUTH_LOCK
const char CustomChar_4[8] PROGMEM = { // padlock
	0b00000,
	0b01110,
	0b01010,
	0b11111,
	0b11011,
	0b11011,
	0b01110,
	0b00000
};
#endif // AUTH_LOCK
#ifdef TIME_LIMIT
const char CustomChar_5[8] PROGMEM = { // time limit clock
	0b00000,
	0b01110,
	0b10001,
	0b11101,
	0b10101,
	0b01110,
	0b00000,
	0b00000
};
#endif // TIME_LIMIT

#ifdef LCD16X2
void OnboardDisplay::MakeChar(uint8_t n, PGM_P bytes)
{
  memcpy_P(g_sTmp, bytes, 8);
  m_Lcd.createChar(n, (uint8_t*)g_sTmp);
}
#endif // LCD16X2

void OnboardDisplay::Init()
{
  WDT_RESET();

#ifdef RGBLCD
  m_bFlags = 0;
#else
  m_bFlags = OBDF_MONO_BACKLIGHT;
#endif // RGBLCD

#ifdef GREEN_LED_REG
  pinGreenLed.init(GREEN_LED_REG,GREEN_LED_IDX,DigitalPin::OUT);
  SetGreenLed(0);
#endif
#ifdef RED_LED_REG
  pinRedLed.init(RED_LED_REG,RED_LED_IDX,DigitalPin::OUT);
  SetRedLed(0);
#endif

#ifdef LCD16X2
  LcdBegin(LCD_MAX_CHARS_PER_LINE, 2);
  LcdSetBacklightColor(WHITE);

#if defined(DELAYTIMER)
  MakeChar(0,CustomChar_6);
#endif
#ifdef DELAYTIMER
  MakeChar(1,CustomChar_1);
  MakeChar(2,CustomChar_2);
#endif //#ifdef DELAYTIMER
#if defined(DELAYTIMER)||defined(CHARGE_LIMIT)
  MakeChar(3,CustomChar_3);
#endif
#ifdef AUTH_LOCK
  MakeChar(4,CustomChar_4);
#endif
#ifdef TIME_LIMIT
  MakeChar(5,CustomChar_5);
#endif // TIME_LIMIT
  m_Lcd.clear();

#ifdef OPENEVSE_2
  LcdPrint_P(0,PSTR("Open EVSE II"));
#else
  LcdPrint_P(0,PSTR("Open EVSE"));
#endif
  LcdPrint_P(0,1,PSTR("Ver. "));
  LcdPrint_P(VERSTR);
  wdt_delay(1500);
  WDT_RESET();
#endif //#ifdef LCD16X2
}

#ifdef LCD16X2
void OnboardDisplay::LcdPrint(int x,int y,const char *s)
{ 
  m_Lcd.setCursor(x,y);
  m_Lcd.print(s); 
}

void OnboardDisplay::LcdPrint_P(PGM_P s)
{
  strncpy_P(m_strBuf,s,LCD_MAX_CHARS_PER_LINE);
  m_strBuf[LCD_MAX_CHARS_PER_LINE] = 0;
  m_Lcd.print(m_strBuf);
}

void OnboardDisplay::LcdPrint_P(int y,PGM_P s)
{
  strncpy_P(m_strBuf,s,LCD_MAX_CHARS_PER_LINE);
  m_strBuf[LCD_MAX_CHARS_PER_LINE] = 0;
  LcdPrint(y,m_strBuf);
}

void OnboardDisplay::LcdPrint_P(int x,int y,PGM_P s)
{
  strncpy_P(m_strBuf,s,LCD_MAX_CHARS_PER_LINE);
  m_strBuf[LCD_MAX_CHARS_PER_LINE] = 0;
  m_Lcd.setCursor(x,y);
  m_Lcd.print(m_strBuf);
}

void OnboardDisplay::LcdMsg_P(PGM_P l1,PGM_P l2)
{
  LcdPrint_P(0,l1);
  LcdPrint_P(1,l2);
}


// print at (0,y), filling out the line with trailing spaces
void OnboardDisplay::LcdPrint(int y,const char *s)
{
  m_Lcd.setCursor(0,y);
  uint8_t i,len = strlen(s);
  if (len > LCD_MAX_CHARS_PER_LINE)
    len = LCD_MAX_CHARS_PER_LINE;
  for (i=0;i < len;i++) {
    m_Lcd.write(s[i]);
  }
  for (i=len;i < LCD_MAX_CHARS_PER_LINE;i++) {
    m_Lcd.write(' ');
  }
}

void OnboardDisplay::LcdMsg(const char *l1,const char *l2)
{
  LcdPrint(0,l1);
  LcdPrint(1,l2);
}
#endif // LCD16X2


void OnboardDisplay::Update(int8_t updmode)
{
  if (updateDisabled() && !g_EvseController.InFaultState()) return;

  uint8_t curstate = g_EvseController.GetState();
#ifdef LCD16X2
//  uint8_t svclvl = g_EvseController.GetCurSvcLevel();
  int currentcap = g_EvseController.GetCurrentCapacity();
#endif
  unsigned long curms = millis();

  if (g_EvseController.StateTransition() || (updmode != OBD_UPD_NORMAL)) {
    curms += 1000; // trigger periodic update code below

    if (g_EvseController.InHardFault()) {
      // need this in case we're called outside of J1772EvseController.HardFault()
      // during a hard fault
      updmode = OBD_UPD_HARDFAULT;
    }

#ifdef LCD16X2
    sprintf(g_sTmp,g_sRdyLAstr,(int)g_EvseController.GetNumPhases(),currentcap);

#endif
    switch(curstate) {
    case EVSE_STATE_A: // not connected
      SetGreenLed(1);
      SetRedLed(0);
#ifdef LCD16X2
      // Display Timer and Stop Icon - GoldServe
      LcdClear();
      LcdSetCursor(0,0);
#ifdef AUTH_LOCK
      if (g_EvseController.AuthLockIsOn()) {
	LcdSetBacklightColor(TEAL);
	LcdWrite(4); 
      }
      else {
	LcdSetBacklightColor(GREEN);
      }
#else
      LcdSetBacklightColor(GREEN);
#endif // AUTH_LOCK
#ifdef DELAYTIMER
      g_DelayTimer.PrintTimerIcon();
#endif //#ifdef DELAYTIMER
      LcdPrint_P(g_psReady);
      LcdPrint(10,0,g_sTmp);

#ifdef KWH_RECORDING 
      sprintf(g_sTmp,STRF_WH,(g_EnergyMeter.GetSessionWs() / 3600) );
      LcdPrint(0,1,g_sTmp);
      
      sprintf(g_sTmp,STRF_KWH,(g_EnergyMeter.GetTotkWh() / 1000));  // display accumulated kWh
      LcdPrint(7,1,g_sTmp);
#endif // KWH_RECORDING
      
#endif //Adafruit RGB LCD
      // n.b. blue LED is off
      break;
    case EVSE_STATE_B: // connected/not charging
      SetGreenLed(1);
      SetRedLed(1);
#ifdef LCD16X2 //Adafruit RGB LCD
      LcdClear();
      LcdSetCursor(0,0);
#ifdef AUTH_LOCK
      if (g_EvseController.AuthLockIsOn()) {
	LcdWrite(4); 
	LcdSetBacklightColor(TEAL);
      }
      else {
	LcdSetBacklightColor(YELLOW);
      }
#else
      LcdSetBacklightColor(YELLOW);
#endif // AUTH_LOCK
#ifdef CHARGE_LIMIT
      if (g_EvseController.GetChargeLimitkWh()) {
	LcdWrite(3); // lightning
      }
#endif
#ifdef TIME_LIMIT
      if (g_EvseController.GetTimeLimit15()) {
	LcdWrite(5); // time limit clock
      }
#endif
      // Display Timer and Stop Icon - GoldServe
#ifdef DELAYTIMER
      g_DelayTimer.PrintTimerIcon();
#endif //#ifdef DELAYTIMER
      LcdPrint_P(g_psEvConnected);
      LcdPrint(10,0,g_sTmp);
     
#ifdef KWH_RECORDING
      sprintf(g_sTmp,STRF_WH,(g_EnergyMeter.GetSessionWs() / 3600) );
      LcdPrint(0,1,g_sTmp);
      
      sprintf(g_sTmp,STRF_KWH,(g_EnergyMeter.GetTotkWh() / 1000));  // display accumulated kWh
      LcdPrint(7,1,g_sTmp);
#endif // KWH_RECORDING
      
#endif //Adafruit RGB LCD
      // n.b. blue LED is off
      break;
    case EVSE_STATE_C: // charging
      SetGreenLed(0);
      SetRedLed(0);
#ifdef LCD16X2 //Adafruit RGB LCD
      LcdSetBacklightColor(TEAL);
      LcdClear();
      LcdSetCursor(0,0);
      // Display Timer and Stop Icon - GoldServe
#ifdef CHARGE_LIMIT
      if (g_EvseController.GetChargeLimitTotWs()) {
	LcdWrite(3); // lightning
      }
#endif
#ifdef TIME_LIMIT
      if (g_EvseController.GetTimeLimit15()) {
	LcdWrite(5); // clock
      }
#endif
#ifdef DELAYTIMER
      g_DelayTimer.PrintTimerIcon();
#endif //#ifdef DELAYTIMER
      LcdPrint_P(g_psCharging);
#endif //Adafruit RGB LCD
      // n.b. blue LED is on
#ifdef AMMETER
      SetAmmeterDirty(1); // force ammeter update code below
#else 
      sprintf(g_sTmp,g_sRdyLAstr,(int)g_EvseController.GetNumPhasesUsed(),currentcap);
      LcdPrint(10,0,g_sTmp);
#endif // AMMETER
      break;
    case EVSE_STATE_D: // vent required
      SetGreenLed(0);
      SetRedLed(1);
#ifdef LCD16X2 //Adafruit RGB LCD
      LcdSetBacklightColor(RED);
      LcdMsg_P(g_psEvseError,g_psVentReq);
#endif //Adafruit RGB LCD
      // n.b. blue LED is off
      break;
    case EVSE_STATE_DIODE_CHK_FAILED:
      SetGreenLed(0);
      SetRedLed(1);
#ifdef LCD16X2 //Adafruit RGB LCD
      LcdSetBacklightColor(RED);
      LcdMsg_P(g_psEvseError,g_psDiodeChkFailed);
#endif //Adafruit RGB LCD
      // n.b. blue LED is off
      break;
    case EVSE_STATE_GFCI_FAULT:
      SetGreenLed(0);
      SetRedLed(1);
#ifdef LCD16X2 //Adafruit RGB LCD
      LcdSetBacklightColor(RED);
      if (updmode == OBD_UPD_HARDFAULT) {
        LcdMsg_P(g_psSvcReq,g_psGfciFault);
      }
      else {
	// 2nd line will be updated below with auto retry count
        LcdPrint_P(0,g_psGfciFault);
      }
#endif //Adafruit RGB LCD
      // n.b. blue LED is off
      break;
#ifdef TEMPERATURE_MONITORING      
    case EVSE_STATE_OVER_TEMPERATURE:    // overtemp message in Red on the RGB LCD
      SetGreenLed(0);
      SetRedLed(1);
#ifdef LCD16X2 //Adafruit RGB LCD
      LcdSetBacklightColor(RED);
      LcdMsg_P(g_psSvcReq,g_psTemperatureFault);  //  SERVICE REQUIRED     OVER TEMPERATURE 
#endif
      break;
#endif //TEMPERATURE_MONITORING        
#ifdef OVERCURRENT_THRESHOLD
    case EVSE_STATE_OVER_CURRENT:
      SetGreenLed(0);
      SetRedLed(1);
#ifdef LCD16X2 //Adafruit RGB LCD
      LcdSetBacklightColor(RED);
      LcdPrint_P(0,g_psSvcReq);
      strcpy_P(g_sTmp,g_psOverCurrent);
      sprintf(g_sTmp+strlen(g_sTmp)," %dA",(int)(g_EvseController.GetChargingCurrent()/1000-g_EvseController.GetCurrentCapacity()));
      LcdPrint(1,g_sTmp);
#endif
      break;
#endif // OVERCURRENT_THRESHOLD   
    case EVSE_STATE_NO_GROUND:
      SetGreenLed(0);
      SetRedLed(1);
#ifdef LCD16X2 //Adafruit RGB LCD
      LcdSetBacklightColor(RED);
      if (updmode == OBD_UPD_HARDFAULT) {
        LcdMsg_P(g_EvseController.CGMIisEnabled() ? g_psSvcReq : g_psEvseError,g_psNoGround);
      }
      else {
	// 2nd line will be updated below with auto retry count
        LcdPrint_P(0,g_psNoGround);
      }
#endif //Adafruit RGB LCD
      // n.b. blue LED is off
      break;
    case EVSE_STATE_STUCK_RELAY:
      SetGreenLed(0);
      SetRedLed(1);
#ifdef LCD16X2 //Adafruit RGB LCD
      LcdSetBacklightColor(RED);
      LcdMsg_P(updmode == OBD_UPD_HARDFAULT ? g_psSvcReq : g_psEvseError,g_psStuckRelay);
#endif //Adafruit RGB LCD
      // n.b. blue LED is off
      break;
    case EVSE_STATE_RELAY_CLOSURE_FAULT:
      SetGreenLed(0);
      SetRedLed(1);
#ifdef LCD16X2 //Adafruit RGB LCD
      LcdSetBacklightColor(RED);
      LcdMsg_P(g_psSvcReq,g_psRelayClosureFault);
#endif //Adafruit RGB LCD
      // n.b. blue LED is off
      break;
    case EVSE_STATE_DISABLED:
      SetGreenLed(0);
      SetRedLed(1);
#ifdef LCD16X2
      LcdSetBacklightColor(VIOLET);
      LcdClear();
      LcdSetCursor(0,0);
#ifdef AUTH_LOCK
      if (g_EvseController.AuthLockIsOn()) {
	LcdWrite(4); 
      }
#endif // AUTH_LOCK
      LcdPrint_P(g_psDisabled);
      LcdPrint(10,0,g_sTmp);
#endif // LCD16X2
      break;
#ifdef GFI_SELFTEST
    case EVSE_STATE_GFI_TEST_FAILED:
      SetGreenLed(0);
      SetRedLed(1);
#ifdef LCD16X2
      LcdSetBacklightColor(RED);
      LcdMsg_P(g_psTestFailed,g_psGfci);
#endif
      break;
#endif // GFI_SELFTEST
    case EVSE_STATE_SLEEPING:
      SetGreenLed(1);
      SetRedLed(1);
#ifdef LCD16X2
      LcdSetBacklightColor(g_EvseController.EvConnected() ? WHITE : VIOLET);
      LcdClear();
      LcdSetCursor(0,0);
#ifdef AUTH_LOCK
      if (g_EvseController.AuthLockIsOn()) {
	LcdWrite(4); 
      }
#endif // AUTH_LOCK
      LcdPrint_P(g_psSleeping);
      LcdPrint(10,0,g_sTmp);
#endif // LCD16X2
      break;
    default:
      SetGreenLed(0);
      SetRedLed(1);
      // n.b. blue LED is off
    }
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
void loop()
{
  WDT_RESET();

  g_EvseController.Update();

#ifdef KWH_RECORDING
  g_EnergyMeter.Update();
#endif // KWH_RECORDING


#ifdef PERIODIC_LCD_REFRESH_MS
  // Force LCD update (required for CE certification testing) to restore LCD if corrupted.
  {
    static unsigned long lastlcdreset = 0;
    if ((millis()-lastlcdreset)>PERIODIC_LCD_REFRESH_MS) {
      g_OBD.Update(OBD_UPD_FORCE);
      lastlcdreset = millis();
    }
    else g_OBD.Update();
  }
#else // !PERIODIC_LCD_REFRESH_MS
  g_OBD.Update();
#endif // PERIODIC_LCD_REFRESH_MS

  ProcessInputs();
  
  // Delay Timer Handler - GoldServe
#ifdef DELAYTIMER
  g_DelayTimer.CheckTime();
#endif //#ifdef DELAYTIMER
}

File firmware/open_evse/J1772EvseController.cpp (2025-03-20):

/*
 * This file is part of Open EVSE.
 *
 * Copyright (c) 2011-2023 Sam C. Lin
 *
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
 * You should have received a copy of the GNU General Public License
 * along with Open EVSE; see the file COPYING.  If not, write to the
 * Free Software Foundation, Inc., 59 Temple Place - Suite 330,
 * Boston, MA 02111-1307, USA.
 */
#include "open_evse.h"

#ifdef FT_ENDURANCE
int g_CycleCnt = -1;
long g_CycleHalfStart;
uint8_t g_CycleState;
#endif

//                                               A/B B/C C/D D DS
THRESH_DATA J1772EVSEController::m_ThreshData = {875,780,690,0,260};

J1772EVSEController g_EvseController;

#ifdef AMMETER
static inline unsigned long ulong_sqrt(unsigned long in)
{
  unsigned long out = 0;
  unsigned long bit = 0x40000000ul;

  // "bit" starts at the highest power of four <= the argument.
  while (bit > in)
    bit >>= 2;

  while (bit) {
    unsigned long sum = out + bit;
    if (in >= sum) {
      in -= sum;
      out = (out >> 1) + bit;
    }
    else
      out >>= 1;
    bit >>= 2;
  }

  return out;
}

void J1772EVSEController::readAmmeter()
{
  WDT_RESET();
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

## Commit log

2023-02-04 Merge OpenEVES/OpenEnergyMonitor changes to the new `master` branch (#14)
    Creating a new master branch fron Lincomatic's master branch with a squash merge of the stable changes from OpenEVSE/OpenEnergyMonitor. This will make it easier to track and merge changes from the upstream repo.
    ---
    * don't enable MENNEKES_LOCK since hardware wont be availabe initally
    * fix merge typo
    * set upload device
    * set BOD fuse
    * set default L2 32A
    * hack to test redrawing the LCD
    * update LCD using OBD_UPD_FORCE
    * update LCD using OBD_UPD_FORCE
    * Revert "update LCD using OBD_UPD_FORCE"
    This reverts commit d31857173b8257a51e2d72ce11a3ec936cf3e1e8.
    * Revert "hack to test redra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
    [J1772EvseController.cpp, open_evse.h, rapi_proc.cpp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]
2023-04-24 Fix missing temperature sensor ( i2c was reset after temp sensor initialisation )
    [main.cpp]
2023-04-24 set default voltage to 230V for EU builds
2025-01-06 Update platformio.ini
    Add support for Continuous Ground Monitoring on OpenEVSE v6+ hardware
2025-03-20 added pcb
    [OpenEVSE_mod-B_Cu.gbr, OpenEVSE_mod-B_Mask.gbr, OpenEVSE_mod-B_Paste.gbr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]
